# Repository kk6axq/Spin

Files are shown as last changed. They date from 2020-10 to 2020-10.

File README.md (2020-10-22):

# Spin
 Spin is a low cost USB volume/mute control device based on the Adafruit Trinket M0. It grew out of the need to have an easy to access volume control during long Zoom meetings.
 
The outer piece is entirely free spinning, thanks to a rotary encoder. Spinning the dial left or right increments and decrements volume of a host computer and pressing down the dial mutes/unmutes the speakers. It can be built in under an hour with less than $20 of parts.
 
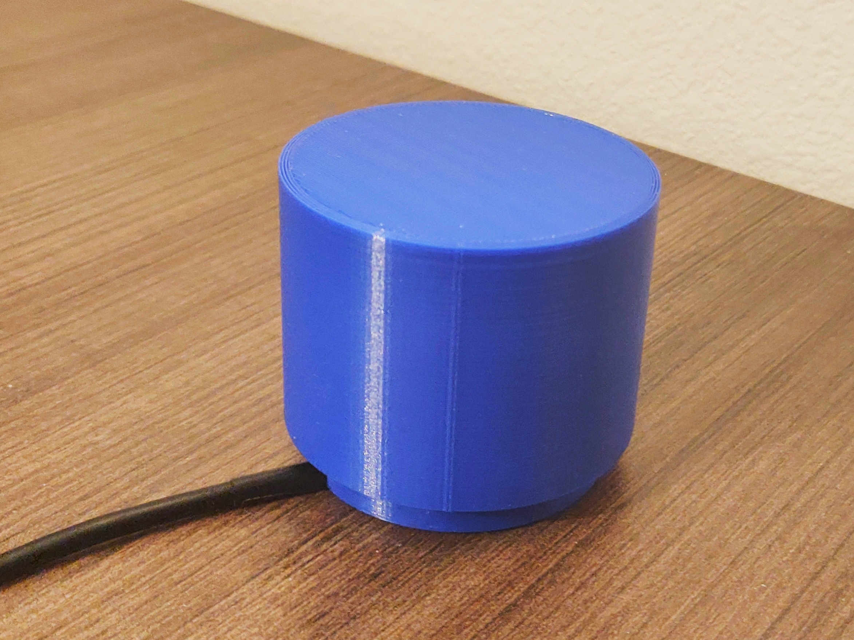
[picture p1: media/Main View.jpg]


## Features
* **Variable speed** The volume is incremented more as the dial is spun faster, allowing for easy control.
* **Sized for easy use** Spin is 2 1/8" (5.5cm) tall and 2.5" (6.3cm) across, it doesn't take up much room but isn't easily lost amongst desk clutter.
* **Customizable** The keys can be easily rebound to other Consumer Control codes, including play/pause, skip, and others. 

## Hardware
Spin's brain is an Adafruit Trinket M0, running CircuitPython. The physical interface is a rotary encoder with integrated button, available cheaply on Amazon. The enclosure is made up of 3 3D printed parts.

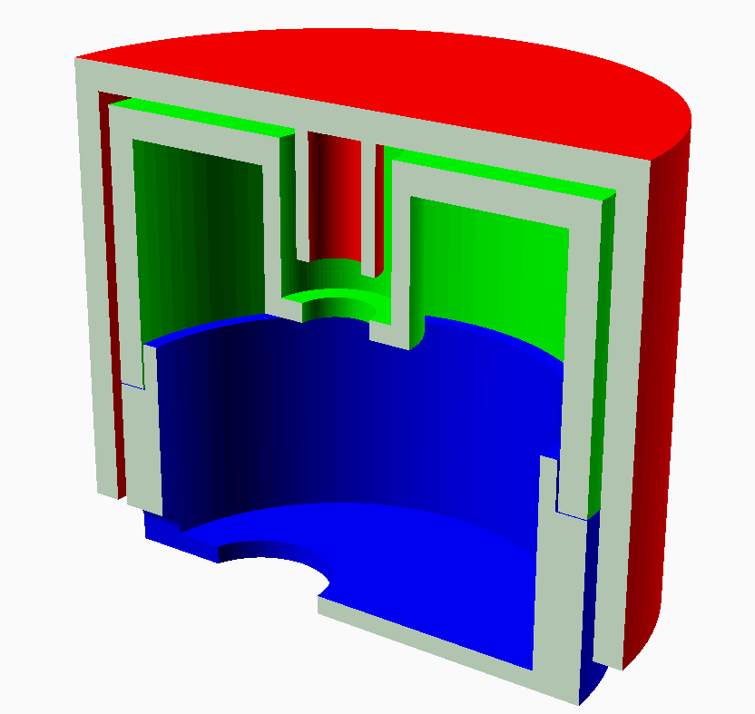
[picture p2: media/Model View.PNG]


## Software
Spin works by emulating a USB HID device and using Consumer Control codes to send volume increment, decrement, and mute commands. It requires no drivers and should work under all operating systems, though it has only been tested with Windows 10. Also, as it runs CircuitPython, no toolchain is required and the device can be dynamically reprogrammed by editing the files within the emulated USB storage.

## Materials
This can be built using parts you may already have on hand. Any CircuitPython compatible board can be used in place of the Trinket.
* 1x Adafruit Trinket M0
* 1x Rotary encoder with pushbutton
* 5x ~4" (10cm) pieces of flexible thin gauge wire
* 1 each of the 3D printed parts
* Miscellaneous: packing tape, thread lock, superglue or hot glue, and solder

## Setup
* **Print the 3 parts.** STL files are provided in the `CAD` folder, and an OpenSCAD file is available for those that want to modify the design. I printed the pieces in PLA with 20% infill, 0.2mm layer height, line supports, and a brim on a Creality CR-10. 
* **Optional: Modify the encoder.** I didn't want the encoder to have detents, so I disassembled it and bent the detent springs flat. To do this:
  * Bend out the tabs holding the outer metal case on.
  * Carefully separate the layers and remove any remaining parts from the plastic case.
  * There will be two D shaped springs molded into the plastic case, bend these back into the recess of the case.
  * Reassemble the case and bend the clips back into place.
* **Wire the encoder.** I recommend using 5 pieces of fairly thing, flexible wire to connect the Trinket and encoder so that there's room to maneuver all the components inside the case.
 * Wire the button:
    * Solder a wire between one of the pins on the two pin side of the encoder and GND on the Trinket.
    * Solder a wire between the other pin on the two pin side and D2 on the Trinket.
  * Wire the encoder:
   * Solder a wire between the middle pin on the three pin side of the encoder and GND on the Trinket.
   * Solder the two remaining wires from the two remaining pins on the three pin side of the encoder to pins D3 and D4. It doesn't matter which pin on the encoder connects to which pin on the Trinket, the direction can be changed easily in the code if they're reversed.
* **Test the wiring.** Connect the Trinket to the computer, and copy the `main.py` file into the root directory of the Trinket's drive. Try rotating the encoder's knob, it should change the volume. Try pressing the button, it should mute and unmute the computer. If one of these doesn't work, double check your wiring. If that doesn't resolve it, open a serial terminal at 9600 baud and see if any error messages are given out when the board is reset.
* **Install the encoder.** Add a drop of blue thread lock to the encoder threads to prevent it from coming loose. Push the encoder through the hole in the inside top piece. The encoder's metal knob should be barely showing above the end of the hole. Slide one of the encoder nuts over the end of the encoder and use tweezers to screw it into place. To make sure it doesn't move, use superglue or hot glue to fix the encoder in place from the back.
* **Assemble the case.** Thread the USB cable through the hole in the bottom piece. Optionally, you can tie a knot in the cable to prevent it from being pulled through. Plug the cable into the Trinket and fit it into the top of the case. If it doesn't fit, try placing it at an angle and fitting the pieces together to see if it closes. Once the pieces fit together, run one layer of packing tape around the outside to hold the pieces together, or add tape as needed on the inside ring to keep the pieces firmly together.

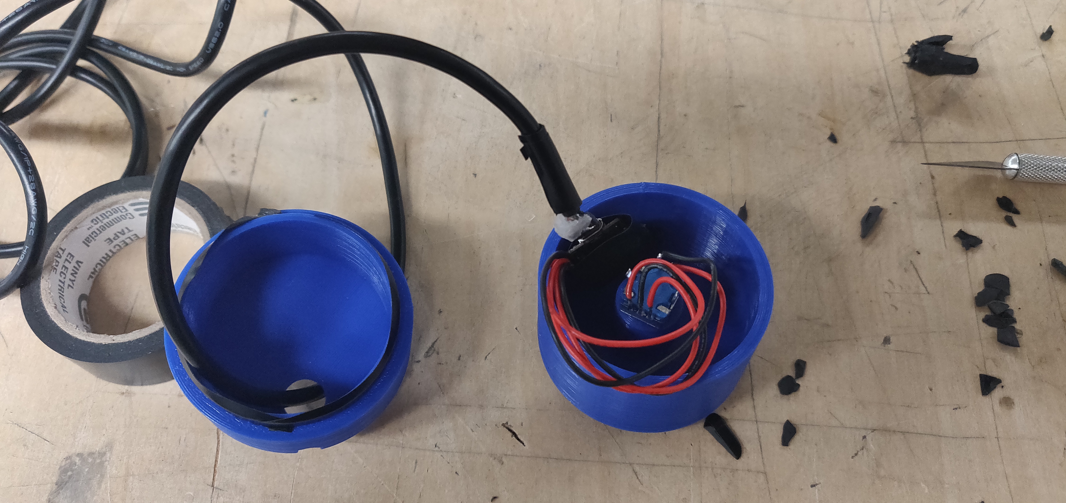
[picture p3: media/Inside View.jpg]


* **Final test.** Plug it into the computer. If everything works, you're done. If not, resolve any issues before putting on the top piece, as it's difficult to separate once it's in place.
* **Final assembly.** Finally, press the top piece onto the encoder knob, making sure to press straight down to not bend it.  

## Material sourcing
The only link that is important is the encoder link. I'm fairly sure it's a generic Chinesium part, but that's the exact product I used, so that's the only one I know will fit (until they change the product).

For the USB cable, it's helpful to have a right angle version to reduce bulkiness inside the case.

|Item|Source|
|---|---|
|Trinket M0|https://www.adafruit.com/product/3500|
|Encoder|https://www.amazon.com/gp/product/B07MW7D4FD/|
|USB Cable|https://www.amazon.com/Cerrxian-Charge-Samsung-Motorola-Android/dp/B01N337FQF/|
|3D Printed Parts||
|Misc (Wire, packing tape, glue)||

## License
Spin is licensed under the GNU GPLv3.

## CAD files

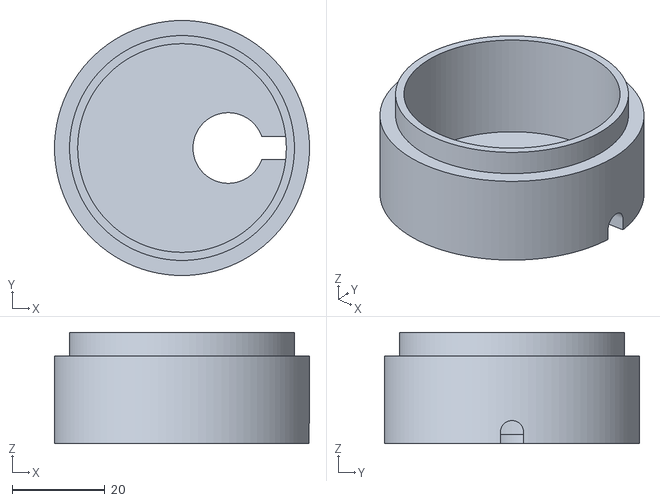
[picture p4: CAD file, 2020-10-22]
CAD/Inner Base.stl
55.0 x 55.0 x 24.1

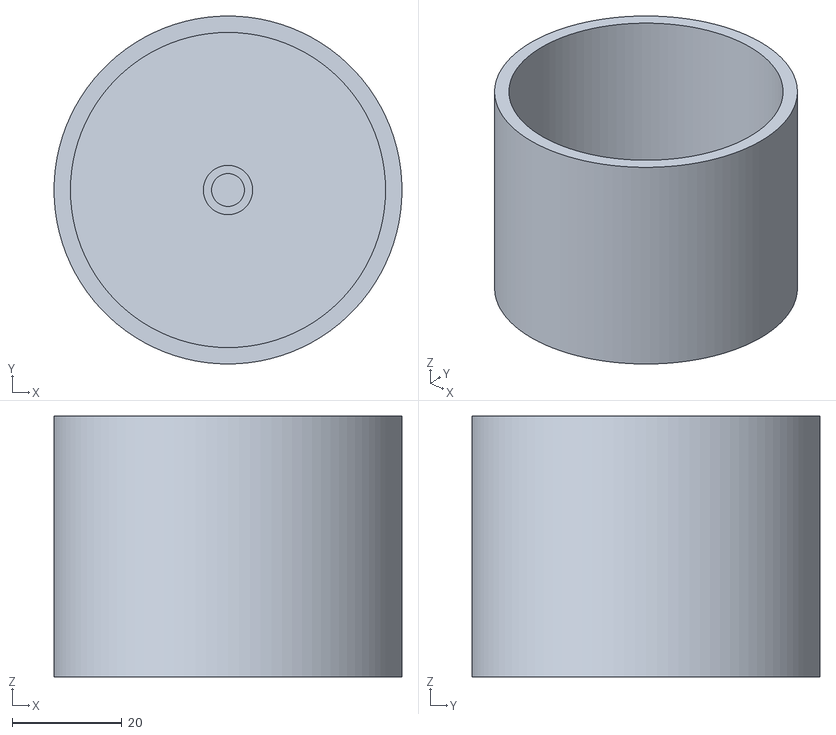
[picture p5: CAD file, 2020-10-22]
CAD/Outer Shell.stl
63.5 x 63.5 x 47.6

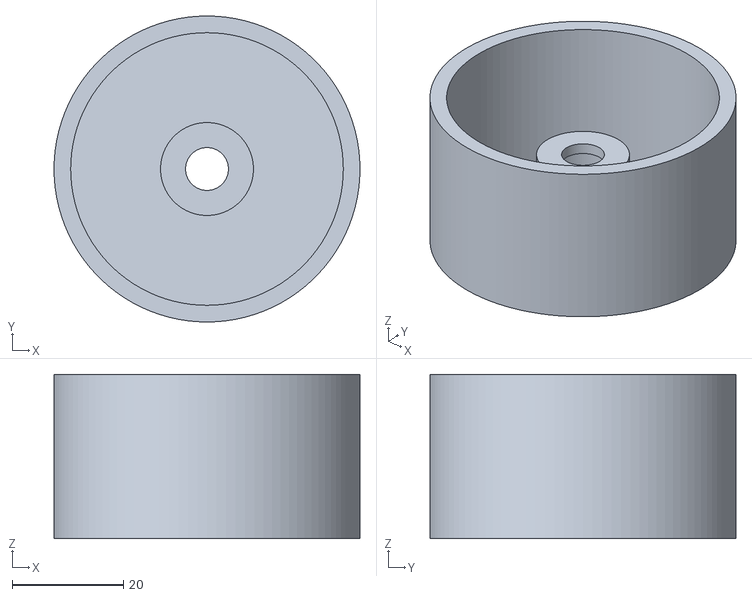
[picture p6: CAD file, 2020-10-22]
CAD/Inner Top.stl
55.0 x 55.0 x 29.6

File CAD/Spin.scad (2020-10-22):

/**
   File: Spin.scad
   Author: Lukas Severinghaus
   Date: October 21, 2020
   Purpose: Design files for Spin volume control.

   License:
   Copyright (C) 2020  Lukas Severinghaus
   This program is free software; you can redistribute it and/or
   modify it under the terms of the GNU General Public License version 3
   as published by the Free Software Foundation;
   This program is distributed in the hope that it will be useful,
   but WITHOUT ANY WARRANTY; without even the implied warranty of
   MERCHANTABILITY or FITNESS FOR A PARTICULAR PURPOSE.  See the
   GNU General Public License for more details.
   You should have received a copy of the GNU General Public License
   along with this program; if not, write to the Free Software
   Foundation, Inc., 51 Franklin Street, Fifth Floor, Boston, MA  02110-1301, USA.
*/

/**** View/Export options ****/
//Set to true to have pieces oriented for 3D printing.
//This inverts some pieces so they don't have to be inverted prior to slicing.
print = true;
//Set to 1 to view all parts 
//Set to 2 to view cross section of all parts
//Set to 3 to view outer piece only.
//Set to 4 to view inner top piece only.
//Set to 5 to view inner base piece only.
slice = 2;

//Circle resolution, set higher for better quality. 100-200 works well, higher than that increase rendering time.
cr = 100;

/**** Variables ****/
i2mm=25.4;
outer_r = 1.25*i2mm;//Radius of outer piece
outer_d = 3;//Depth of top outer edge
outer_wall = 3;//Wall thickness of outer piece
outer_h = 1.875*i2mm;
knob_hole = 6;//Knob diameter
knob_thick = 1.5; //Thickness of wall around knob
thread_hole = 7.7;
knob_height = 0.5*i2mm;

inner_r = 1.103*i2mm-0.5;//Radius of inner piece
inner_h = 1.8356 * i2mm + 2;//Height of inner piece
inner_top_d = 3; //Depth of top of inner
inner_thick = 3;

base_h = 0.75 * i2mm;//Height of the base
base_d = 2; //Thickness of the base
base_o = 2;//Overlap of the base
base_l = 5;//Overlap height
base_t = 0.25;//Overlap tolerance

tube_d = 2;//Thickness of flat part of inner hole
tube_r = 0.25 * i2mm; //Radius of inner hole
tube_t = 2;//Wall thickness of inner hole
tube_h = 0.7 * i2mm - tube_d;//Depth of inner hole
tube_hole_r = 3.85;

cable_r = 2.5;


module cut_plane(){
    translate([-50, 0, -0.1]) cube([100, 100, 100]);
}
module cut_plane_r(z){
    rotate([0, 0, z]) translate([-50, 0, -0.1]) cube([100, 100, 100]);
}
//Outer upper piece
module outer(){
    translate([0, 0, outer_h]) rotate([180, 0, 0]){
    union(){
        cylinder(outer_d, r1=outer_r, r2=outer_r, $fn=cr);
        difference(){
            cylinder(outer_h, r1=outer_r, r2=outer_r, $fn=cr);
            cylinder(outer_h+0.01, r1=outer_r-outer_wall, r2=outer_r-outer_wall, $fn=cr);
        }
        difference(){
            cylinder(knob_height+outer_d, r1=(knob_hole / 2) + knob_thick, r2=(knob_hole / 2) + knob_thick, $fn=cr);
            cylinder(knob_height+outer_d+0.01, r1=(knob_hole / 2), r2=(knob_hole / 2), $fn=cr);
        }
    }
}
}

module inner(){
  union(){
      difference(){
          //Outer cylinder
          cylinder(inner_h-base_h, r1=inner_r, r2=inner_r, $fn=cr);
          //Inner cylinder cut
          translate([0, 0, -0.1]) cylinder(inner_h - inner_top_d + 0.1 - base_h, r1 = inner_r - inner_thick, r2=inner_r-inner_thick, $fn=cr);
          //Top hole
          cylinder(inner_h + 0.3 - base_h, r1=tube_r, r2=tube_r, $fn=cr);
      }
      //Encoder slot/hole
      translate([0, 0, inner_h - (tube_h + tube_d) - base_h]) difference(){
      translate([0, 0, 0]) cylinder(tube_h+tube_d, r1=tube_r+tube_t, r2=tube_r+tube_t, $fn=cr);
      translate([0, 0, -0.1]) cylinder(tube_d + 0.2, r1=tube_hole_r, r2=tube_hole_r, $fn=cr);
      translate([0, 0, tube_d]) cylinder(tube_h+0.1, r1=tube_r, r2=tube_r, $fn=cr);    
          
      }
      
  }
}

module inner_base(){
    difference(){
    union(){
    cylinder(base_h-0.1, r1=inner_r, r2=inner_r, $fn=cr);
    cylinder(base_h + base_l, r1=inner_r - inner_thick-base_t, r2=inner_r - inner_thick-base_t, $fn=cr);
    }
    //Inner cylinder cut
    translate([0, 0, base_d]) cylinder(base_h - base_d + 0.1+20, r1 = inner_r - inner_thick-base_o, r2=inner_r-inner_thick-base_o, $fn=cr);
    //Cable hole
    translate([15, 0, 2.5]) rotate([0, 90, 0]) cylinder(100, r1=cable_r, r2=cable_r, $fn=cr);
          //Cable hole slot
    translate([15, -1 * cable_r, -0.1]) cube([100, cable_r*2, cable_r+0.1]);
    translate([10, 0, -0.1]) cylinder(10, r1=0.3*i2mm, r2=0.3*i2mm, $fn=cr);
    }
}

if(slice == 1){
    translate([0, 0, base_h]) inner();
    inner_base();
    translate([0, 0, 0.125 *i2mm + 2]) outer();
}else if(slice == 2){
    difference(){
        translate([0, 0, base_h]) color([0, 1, 0]) inner(); cut_plane();
    }
    difference(){
        color([0, 0, 1]) inner_base();
        cut_plane_r(0);
    }
    difference() {
        translate([0, 0, 0.125 *i2mm + 2]) color([1, 0, 0]) outer();
        cut_plane_r(0);
    }

}else if(slice == 3){
    rotate([0, print ? 180 : 0, 0]) outer();
}else if(slice == 4){
    rotate([0, print ? 180 : 0, 0]) inner();
}else if(slice == 5){
    inner_base();
}

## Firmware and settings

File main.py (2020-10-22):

import time
import board
from digitalio import DigitalInOut, Direction, Pull
from adafruit_hid.consumer_control import ConsumerControl
from adafruit_hid.consumer_control_code import ConsumerControlCode
import usb_hid
import rotaryio

consumer_control = ConsumerControl(usb_hid.devices)

encoder = rotaryio.IncrementalEncoder(board.D3, board.D4)

led = DigitalInOut(board.D1)
led.direction = Direction.OUTPUT



switch = DigitalInOut(board.D2)
switch.direction = Direction.INPUT
switch.pull = Pull.UP

led.value=True
time.sleep(0.5)
led.value=False



p_enc_pos = 0
p_enc_time = 0
multi = False
multi_count = 0
repeat_thresh = 0.04
start_time = 0
while True:
    # We could also do "led.value = not switch.value"!
    if switch.value:
        led.value = False
    else:
        led.value = True
        consumer_control.send(ConsumerControlCode.MUTE)
        time.sleep(0.3)
    if encoder.position != p_enc_pos:
        start_time = time.monotonic()
        delta_t = start_time - p_enc_time
        print(int(delta_t * 100))
        #Checks if time between ticks is less than threshold
        if delta_t < repeat_thresh:
            multi = True
        #Can multi-click up to 4 times depending on how fast it ticks
        multi_count = (repeat_thresh * 100) - int(delta_t * 100)
        #Change the < to > here if it's incrementing in the wrong direction
        if encoder.position < p_enc_pos:
            if multi:
                for i in range(multi_count):
                    consumer_control.send(ConsumerControlCode.VOLUME_INCREMENT)
                    print("Multi Increment")
            else:
                consumer_control.send(ConsumerControlCode.VOLUME_INCREMENT)
                print("Single Increment")
        else:
            if multi:
                for i in range(multi_count):
                    consumer_control.send(ConsumerControlCode.VOLUME_DECREMENT)
                    print("Multi Decrement")
            else:
                 consumer_control.send(ConsumerControlCode.VOLUME_DECREMENT)
                 print("Single Decrement")
        p_enc_pos = encoder.position
        p_enc_time = start_time
        multi = False
